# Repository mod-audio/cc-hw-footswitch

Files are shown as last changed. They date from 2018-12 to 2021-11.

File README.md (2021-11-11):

mod-hw-footswitch
=================

This repository contains the schematics and PCB design files for the Footswitch hardware.
This is a peripheral meant to be used in conjunction with MOD (http://moddevices.com/) via its control-chain interface.

These files were created and can be improved with KiCAD, a free software Electronics CAD which is available at http://www.kicad.org/

## Check out instructions ##

This project uses a set of KiCAD symbols and footprints provided by the official KiCad library (https://github.com/KiCad/). In order to properly fetch these dependencies, which are configured as submodule repositories, you have to use the **--recursive** attribute in the following **git** command:

> git clone --recursive https://github.com/portalmod/mod-hw-footswitch.git

## Licensing ##

This is an Open Hardware project and all of the files in this repository are licensed under the terms of the "Creative Commons By-SA" license.

## Firmware ##

The firmware source code is freely available at https://github.com/portalmod/mod-fw-footswitch

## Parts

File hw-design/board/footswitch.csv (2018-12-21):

Item | Qty | Reference(s) | Value | LibPart | Footprint | Datasheet | MPN | Note
1 | 9 | C1, C7, C9, C11, C12, C13, C14, C15, C21 | 100nF | footswitch-rescue:C | Capacitors_SMD:C_0603 | ~ | C1608X7R1E104K080AA
2 | 3 | C2, C8, C16 | 10uF | footswitch-rescue:C | Capacitors_SMD:C_0805 |  | GRM219R61E106KA12D
3 | 2 | C3, C17 | 1uF | footswitch-rescue:C | Capacitors_SMD:C_0805 |  | C2012X7R1E105K125AB
4 | 2 | C4, C6 | 18pF | footswitch-rescue:C | Capacitors_SMD:C_0603 |  | C1608C0G1H180J080AA
5 | 1 | C5 | 10uF | footswitch-rescue:CP1 | Capacitors_SMD:c_elec_5x5.3 | ~ | UWX1E100MCL1GB
6 | 1 | C10 | 100uF | footswitch-rescue:CP1 | Capacitors_SMD:c_elec_6.3x5.3 | ~ | UWX1C101MCL1GB
7 | 1 | C19 | 10nF 500V | footswitch-rescue:C | Capacitors_SMD:C_1206 |  | 501R18W103KV4E
8 | 1 | D1 | CGRA4007-G | footswitch-rescue:D | Diodes_SMD:Diode-SMA_Standard | ~ | CGRA4007-G
9 | 1 | D2 | 1N4148 | footswitch-rescue:D | Diodes_SMD:SOD-323 |  | 1N4148WX-TP
10 | 1 | D3 | 1N5819 | footswitch-rescue:D_Schottky | Diodes_SMD:SOD-123 |  | 1N5819HW-7-F
11 | 4 | D5, D6, D7, D8 | LED_RGB | footswitch-rescue:LED_RGB | LEDs:LED-RGB_PLLC-6 |  | LTRBGFSF-ABCB-QKYO-Z
12 | 2 | DS1, DS2 | ERM1602FS-6 3.3V | footswitch-rescue:RC1602A-GHW-ESX | local-footprints:WC1602A |  | ERM1602FS-6 3.3V | 3.3V display
13 | 6 | H1, H2, H3, H4, H5, H6 | HOLE | footswitch-rescue:CONN_01X01 | local-footprints:M3-screw-hole |  |  | not a component
14 | 2 | H7, H8 | KEYSTONE | footswitch-rescue:CONN_02X02 | local-footprints:Keystone-7790 |  | Keystone 7790
15 | 1 | J1 | CC_MAIN | footswitch-rescue:RJ45 | local-footprints:54602-908LF |  | 54602-908LF
16 | 1 | J2 | CC_NEXT | footswitch-rescue:RJ45 | local-footprints:54602-908LF |  | 54602-908LF
17 | 4 | P1, P2, P4, P5 | FOOT | footswitch-rescue:CONN_01X02 | Pin_Headers:Pin_Header_Angled_1x02 |  | M20-9960245 | place on the back side
18 | 1 | P3 | CHAIN | footswitch-rescue:CONN_01X03 | Pin_Headers:Pin_Header_Straight_1x03 |  |  | do not place
19 | 1 | P6 | CONN_01X12 | footswitch-rescue:CONN_01X12 | Pin_Headers:Pin_Header_Straight_1x12 |  | 68016-112HLF
20 | 1 | P7 | USB_OTG | footswitch-rescue:USB_OTG | Connect:USB_Mini-B |  | 10033526-N3212LF
21 | 1 | P8 | CONN_01X12 | footswitch-rescue:CONN_01X12 | Pin_Headers:Pin_Header_Angled_1x12 |  | 68016-112HLF
22 | 1 | P9 | SWD | footswitch-rescue:CONN_02X05 | Pin_Headers:Pin_Header_Straight_2x05_Pitch1.27mm |  |  | do not place
23 | 1 | P10 | CPU_RESET | footswitch-rescue:CONN_01X02 | Resistors_SMD:R_0402 |  |  | do not place
24 | 5 | Q1, Q3, Q4, Q7, Q8 | 2N7002 | footswitch-rescue:Q_NMOS_GSD | Housings_SOT-23_SOT-143_TSOT-6:SOT-23 |  | 2N7002P,215
25 | 1 | Q2 | BC857 | footswitch-rescue:Q_PNP_BEC | Housings_SOT-23_SOT-143_TSOT-6:SOT-23 |  | BC857B,215
26 | 1 | Q5 | FDN306P | footswitch-rescue:Q_PMOS_GSD | local-footprints:SOT-23-fairchild |  | FDN306P_F095
27 | 1 | Q6 | IRFML8244TRPBF | footswitch-rescue:Q_NMOS_GSD | Housings_SOT-23_SOT-143_TSOT-6:SOT-23 |  | IRFML8244TRPBF
28 | 13 | R1, R2, R3, R4, R8, R10, R11, R12, R13, R17, R18, R39, R40 | 10K | footswitch-rescue:R | Resistors_SMD:R_0603 | ~ | RMCF0603JT10K0
29 | 1 | R5 | 3K | footswitch-rescue:R | Resistors_SMD:R_0603 |  | MCR03ERTF3001
30 | 3 | R6, R19, R38 | 100K | footswitch-rescue:R | Resistors_SMD:R_0603 |  | RMCF0603JT100K
31 | 1 | R7 | 24K | footswitch-rescue:R | Resistors_SMD:R_0603 |  | MCR03ERTF2402
32 | 2 | R9, R21 | 2K4 | footswitch-rescue:R | Resistors_SMD:R_0603 |  |  | do not place
33 | 1 | R14 | 1K5 | footswitch-rescue:R | Resistors_SMD:R_0603 |  | MCR03ERTF1501
34 | 2 | R15, R22 | 1.2K | footswitch-rescue:R | Resistors_SMD:R_0603 |  | RMCF0603JT1K20
35 | 1 | R16 | 100R | footswitch-rescue:R | Resistors_SMD:R_0805 |  | ERJ-P06F1000V
36 | 1 | R20 | 100R | footswitch-rescue:R | Resistors_SMD:R_0603 |  | RMCF0603JT100R
37 | 12 | R23, R24, R25, R28, R29, R30, R31, R32, R33, R34, R35, R36 | 220R | footswitch-rescue:R | Resistors_SMD:R_0603 | ~ | RMCF0603JT220R
38 | 2 | R26, R27 | 33R | footswitch-rescue:R | Resistors_SMD:R_0603 |  | MCR03ERTF33R0
39 | 1 | R37 | 1M | footswitch-rescue:R | Resistors_SMD:R_0603 |  | RMCF0603JT1M00
40 | 1 | RT1 | PTC_FUSE | footswitch-rescue:FUSE | Resistors_SMD:R_1210 | ~ | 0ZCB0050FF2G
41 | 1 | U1 | ISL83491 | footswitch-rescue:ISL83491 | Housings_SOIC:SOIC-14_3.9x8.7mm_Pitch1.27mm |  | ISL83491IBZ
42 | 1 | U2 | NCP1117DT33G | footswitch-rescue:NCP1117ST33T3G | SMD_Packages:DPAK-2 |  | NCP1117DT33G
43 | 1 | U3 | LPC11U24FBD48/401 | footswitch-rescue:LPC11U24FBD48_401 | Housings_QFP:LQFP-48_7x7mm_Pitch0.5mm |  | LPC11U24FBD48/401
44 | 1 | Y1 | 12MHz | footswitch-rescue:Crystal_Small | Crystals:Crystal_HC49-SD_SMD |  | FOXSDLF/120-20

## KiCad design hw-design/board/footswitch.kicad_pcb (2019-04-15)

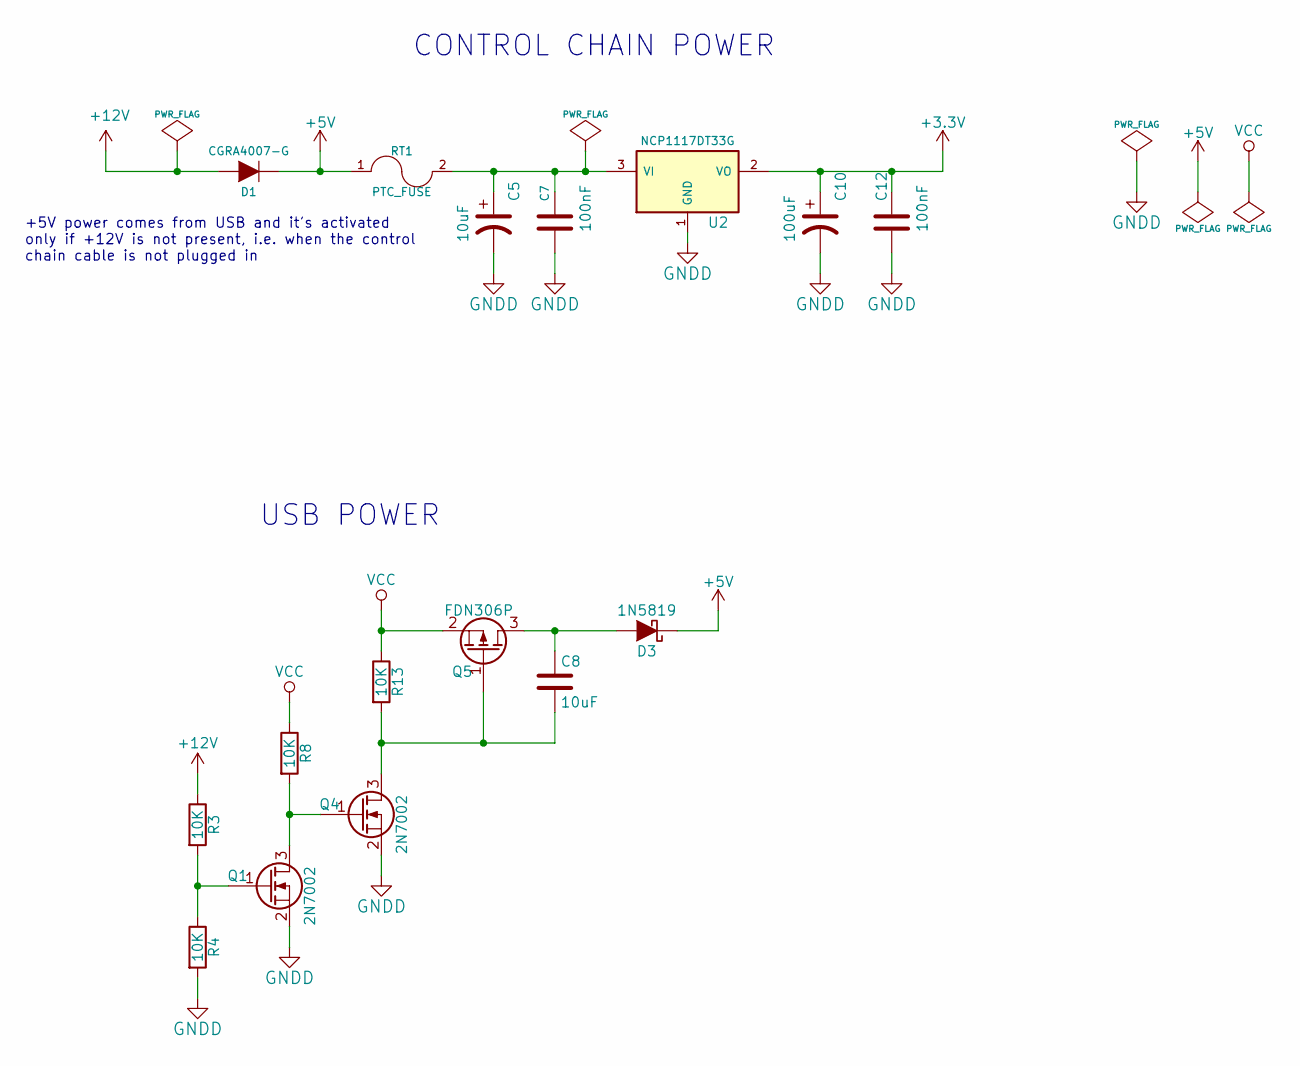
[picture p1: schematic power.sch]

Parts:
C5: 10uF; c_elec_5x5.3; MPN UWX1E100MCL1GB
C7, C12: 100nF; C_0603; MPN C1608X7R1E104K080AA
C8: 10uF; C_0805; MPN GRM219R61E106KA12D
C10: 100uF; c_elec_6.3x5.3; MPN UWX1C101MCL1GB
D1: CGRA4007-G; Diode-SMA_Standard; MPN CGRA4007-G
D3: 1N5819; SOD-123; MPN 1N5819HW-7-F
Q1, Q4: 2N7002; SOT-23; MPN 2N7002P,215
Q5: FDN306P; SOT-23-fairchild; MPN FDN306P_F095
R3, R4, R8, R13: 10K; R_0603; MPN RMCF0603JT10K0
RT1: PTC_FUSE; R_1210; MPN 0ZCB0050FF2G
U2: NCP1117DT33G; DPAK-2; MPN NCP1117DT33G

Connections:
+3V3: C10.1, C12.1, U2.2 (VO); also elsewhere on the board
+5V: D1.1 (K), D3.1 (K), RT1.1
+12V: D1.2 (A), R3.1; also elsewhere on the board
GNDD: C5.2, C7.2, C10.2, C12.2, Q1.2 (S), Q4.2 (S), R4.2, U2.1 (GND); also elsewhere on the board
unnamed: C5.1, C7.1, RT1.2, U2.3 (VI)
unnamed: C8.1, D3.2 (A), Q5.3 (D)
unnamed: C8.2, Q4.3 (D), Q5.1 (G), R13.2
unnamed: Q1.1 (G), R3.2, R4.1
unnamed: Q1.3 (D), Q4.1 (G), R8.2
USB_VCC: Q5.2 (S), R8.1, R13.1; also elsewhere on the board

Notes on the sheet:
CONTROL CHAIN POWER
USB POWER
+5V power comes from USB and it's activated only if +12V is not present, i.e. when the control chain cable is not plugged in

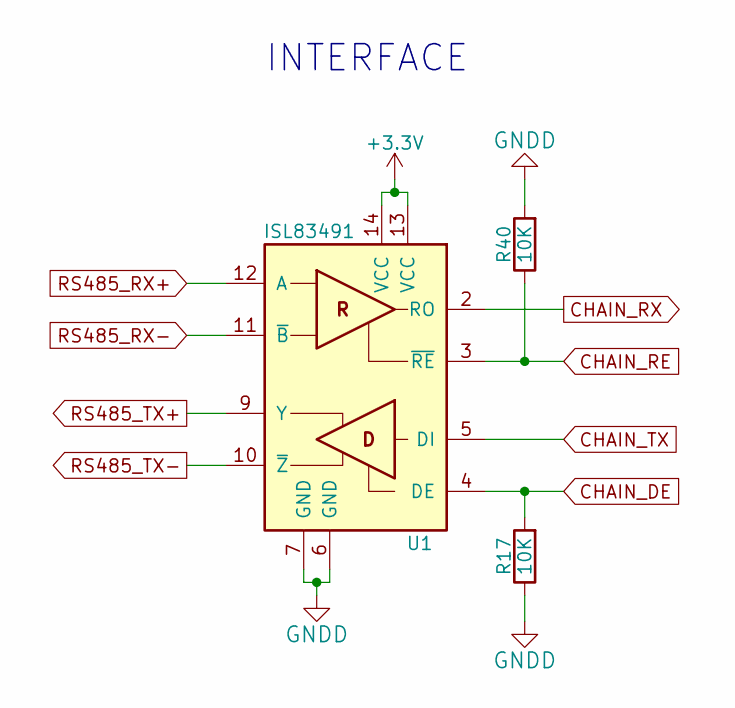
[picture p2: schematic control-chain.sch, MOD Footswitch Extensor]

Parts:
R17, R40: 10K; R_0603; MPN RMCF0603JT10K0
U1: ISL83491; SOIC-14_3.9x8.7mm_Pitch1.27mm; MPN ISL83491IBZ

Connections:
+3V3: U1.13 (VCC), U1.14 (VCC); also elsewhere on the board
CHAIN_DE: R17.2, U1.4 (DE); also elsewhere on the board
CHAIN_RE: R40.1, U1.3 (~RE); also elsewhere on the board
CHAIN_RX: U1.2 (RO); also elsewhere on the board
CHAIN_TX: U1.5 (DI); also elsewhere on the board
GNDD: R17.1, R40.2, U1.6 (GND), U1.7 (GND); also elsewhere on the board
RS485_RX+: U1.12 (A); also elsewhere on the board
RS485_RX-: U1.11 (~B); also elsewhere on the board
RS485_TX+: U1.9 (Y); also elsewhere on the board
RS485_TX-: U1.10 (~Z~); also elsewhere on the board

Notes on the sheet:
INTERFACE

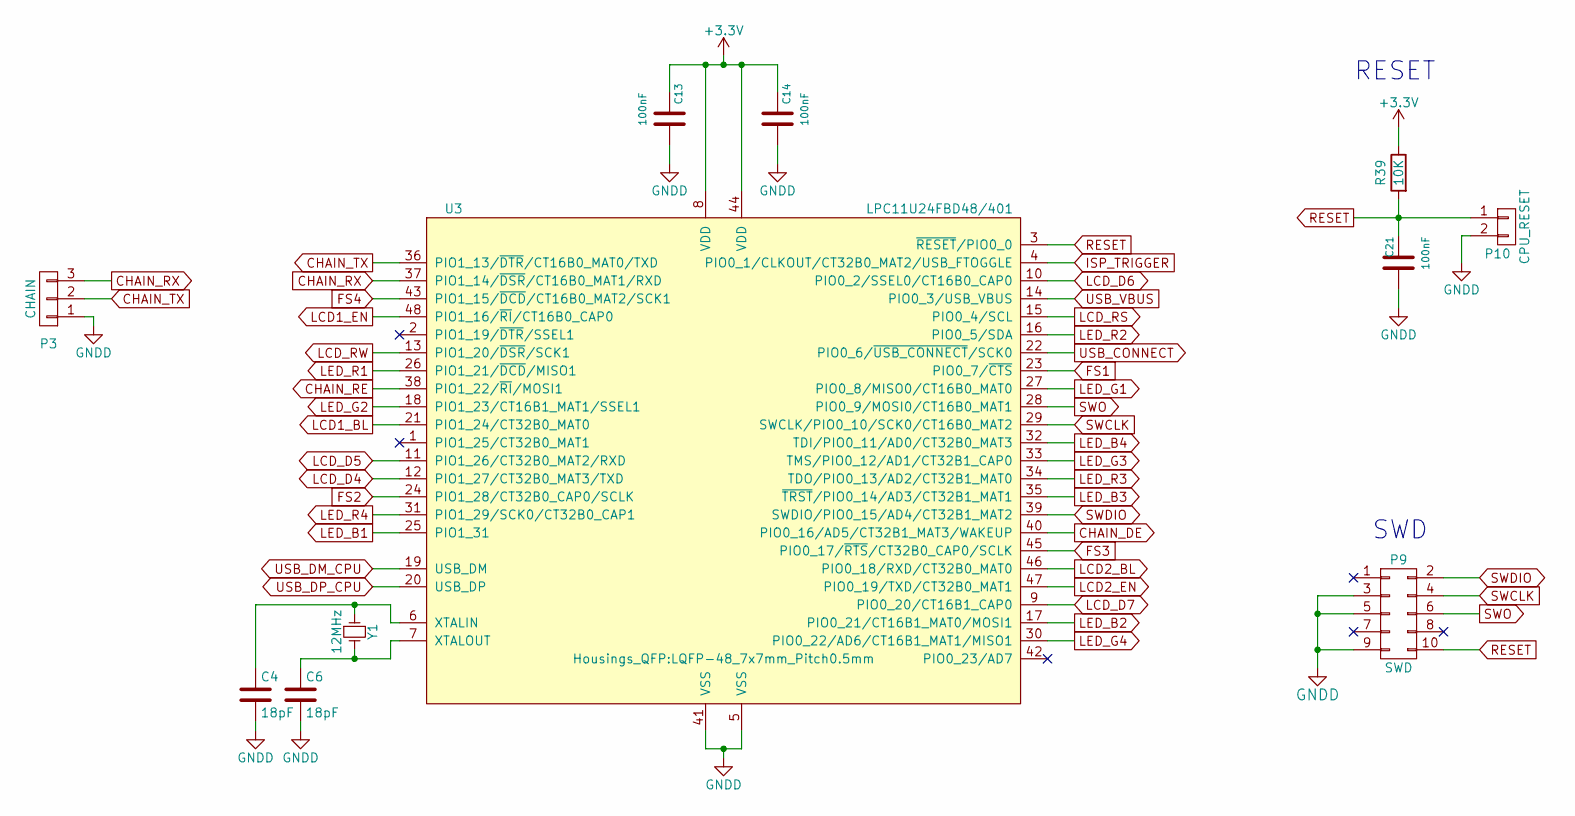
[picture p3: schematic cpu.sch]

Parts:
C4, C6: 18pF; C_0603; MPN C1608C0G1H180J080AA
C13, C14, C21: 100nF; C_0603; MPN C1608X7R1E104K080AA
P3: CHAIN; Pin_Header_Straight_1x03
P9: SWD; Pin_Header_Straight_2x05_Pitch1.27mm
P10: CPU_RESET; R_0402
R39: 10K; R_0603; MPN RMCF0603JT10K0
U3: LPC11U24FBD48/401; LQFP-48_7x7mm_Pitch0.5mm; MPN LPC11U24FBD48/401
Y1: 12MHz; Crystal_HC49-SD_SMD; MPN FOXSDLF/120-20

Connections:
+3V3: C13.2, C14.2, R39.1, U3.8 (VDD), U3.44 (VDD); also elsewhere on the board
CHAIN_DE: U3.40 (PIO0_16/AD5/CT32B1_MAT3/WAKEUP); also elsewhere on the board
CHAIN_RE: U3.38 (PIO1_22/~RI~/MOSI1); also elsewhere on the board
CHAIN_RX: P3.3, U3.37 (PIO1_14/~DSR~/CT16B0_MAT1/RXD); also elsewhere on the board
CHAIN_TX: P3.2, U3.36 (PIO1_13/~DTR~/CT16B0_MAT0/TXD); also elsewhere on the board
FS1: U3.23 (PIO0_7/~CTS~); also elsewhere on the board
FS2: U3.24 (PIO1_28/CT32B0_CAP0/SCLK); also elsewhere on the board
FS3: U3.45 (PIO0_17/~RTS~/CT32B0_CAP0/SCLK); also elsewhere on the board
FS4: U3.43 (PIO1_15/~DCD~/CT16B0_MAT2/SCK1); also elsewhere on the board
GNDD: C4.2, C6.2, C13.1, C14.1, C21.1, P3.1, P9.3, P9.5, P9.9, P10.2, U3.5 (VSS), U3.41 (VSS); also elsewhere on the board
ISP_TRIGGER: U3.4 (PIO0_1/CLKOUT/CT32B0_MAT2/USB_FTOGGLE); also elsewhere on the board
LCD1_BL: U3.21 (PIO1_24/CT32B0_MAT0); also elsewhere on the board
LCD1_EN: U3.48 (PIO1_16/~RI~/CT16B0_CAP0); also elsewhere on the board
LCD2_BL: U3.46 (PIO0_18/RXD/CT32B0_MAT0); also elsewhere on the board
LCD2_EN: U3.47 (PIO0_19/TXD/CT32B0_MAT1); also elsewhere on the board
LCD_D4: U3.12 (PIO1_27/CT32B0_MAT3/TXD); also elsewhere on the board
LCD_D5: U3.11 (PIO1_26/CT32B0_MAT2/RXD); also elsewhere on the board
LCD_D6: U3.10 (PIO0_2/SSEL0/CT16B0_CAP0); also elsewhere on the board
LCD_D7: U3.9 (PIO0_20/CT16B1_CAP0); also elsewhere on the board
LCD_RS: U3.15 (PIO0_4/SCL); also elsewhere on the board
LCD_RW: U3.13 (PIO1_20/~DSR~/SCK1); also elsewhere on the board
LED_B1: U3.25 (PIO1_31); also elsewhere on the board
LED_B2: U3.17 (PIO0_21/CT16B1_MAT0/MOSI1); also elsewhere on the board
LED_B3: U3.35 (~TRST~/PIO0_14/AD3/CT32B1_MAT1); also elsewhere on the board
LED_B4: U3.32 (TDI/PIO0_11/AD0/CT32B0_MAT3); also elsewhere on the board
LED_G1: U3.27 (PIO0_8/MISO0/CT16B0_MAT0); also elsewhere on the board
LED_G2: U3.18 (PIO1_23/CT16B1_MAT1/SSEL1); also elsewhere on the board
LED_G3: U3.33 (TMS/PIO0_12/AD1/CT32B1_CAP0); also elsewhere on the board
LED_G4: U3.30 (PIO0_22/AD6/CT16B1_MAT1/MISO1); also elsewhere on the board
LED_R1: U3.26 (PIO1_21/~DCD~/MISO1); also elsewhere on the board
LED_R2: U3.16 (PIO0_5/SDA); also elsewhere on the board
LED_R3: U3.34 (TDO/PIO0_13/AD2/CT32B1_MAT0); also elsewhere on the board
LED_R4: U3.31 (PIO1_29/SCK0/CT32B0_CAP1); also elsewhere on the board
unnamed: C4.1, U3.6 (XTALIN), Y1.1
unnamed: C6.1, U3.7 (XTALOUT), Y1.2
RESET: C21.2, P9.10, P10.1, R39.2, U3.3 (~RESET~/PIO0_0)
SWCLK: P9.4, U3.29 (SWCLK/PIO0_10/SCK0/CT16B0_MAT2)
SWDIO: P9.2, U3.39 (SWDIO/PIO0_15/AD4/CT32B1_MAT2)
SWO: P9.6, U3.28 (PIO0_9/MOSI0/CT16B0_MAT1)
USB_CONNECT: U3.22 (PIO0_6/~USB_CONNECT~/SCK0); also elsewhere on the board
USB_DM_CPU: U3.19 (USB_DM); also elsewhere on the board
USB_DP_CPU: U3.20 (USB_DP); also elsewhere on the board
USB_VBUS: U3.14 (PIO0_3/USB_VBUS); also elsewhere on the board

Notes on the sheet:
SWD
RESET

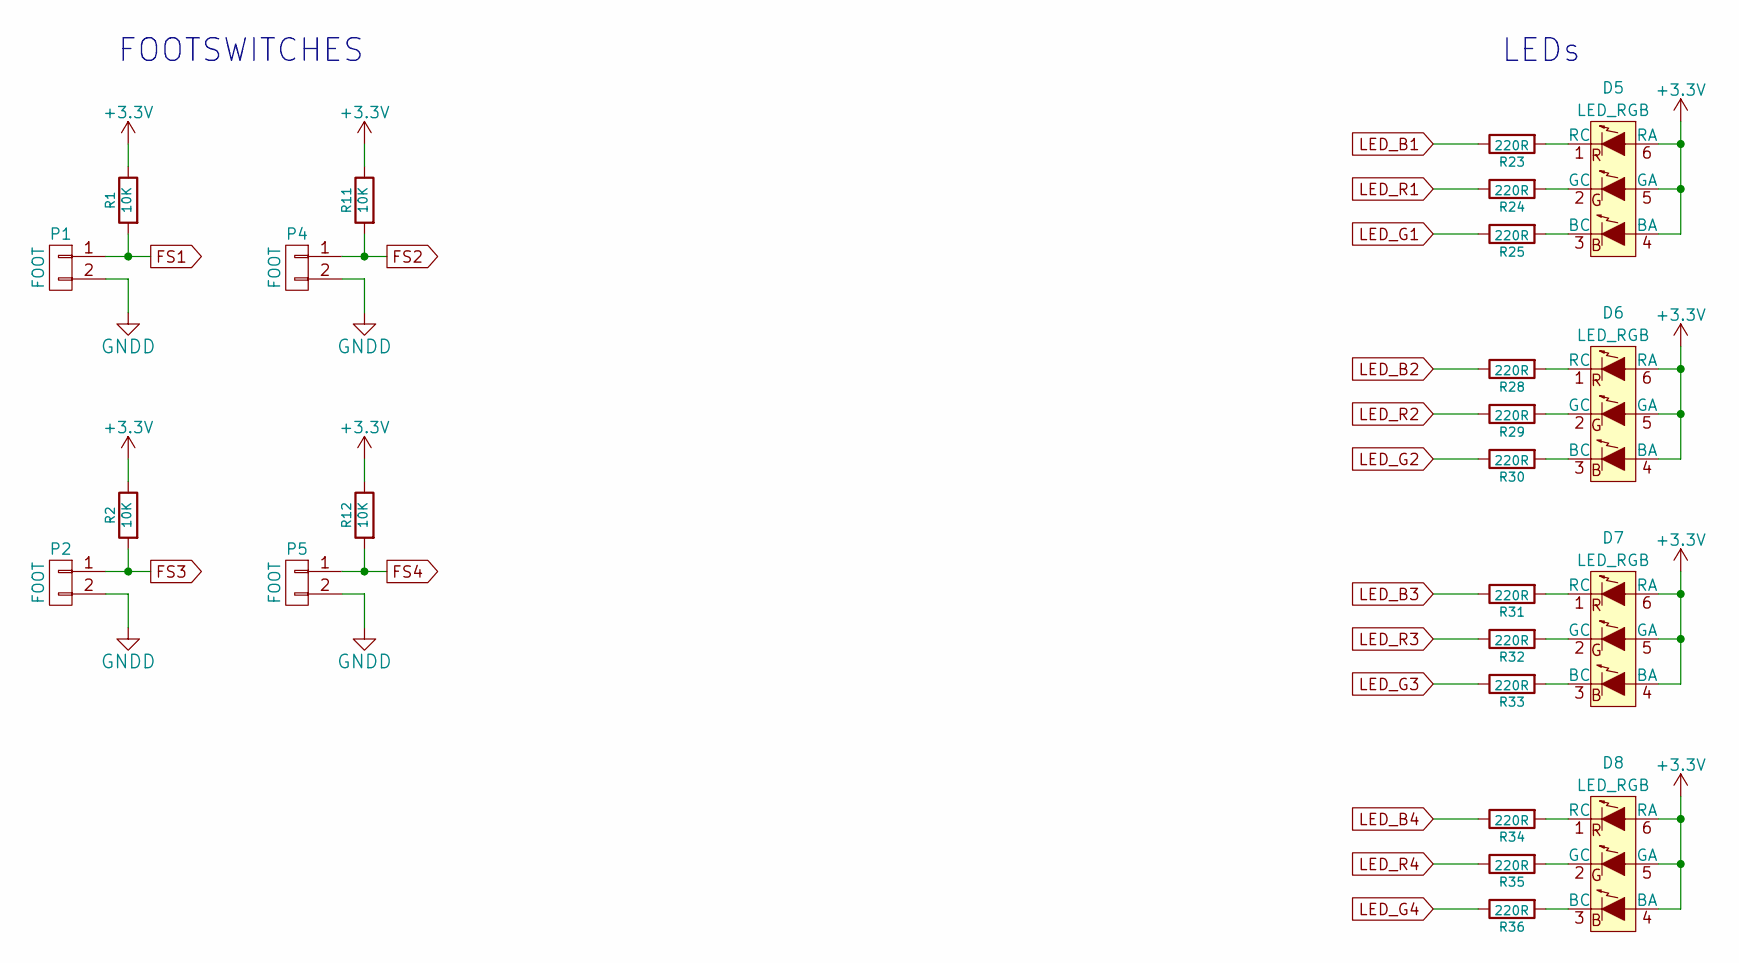
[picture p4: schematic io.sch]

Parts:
D5, D6, D7, D8: LED_RGB; LED-RGB_PLLC-6; MPN LTRBGFSF-ABCB-QKYO-Z
P1, P2, P4, P5: FOOT; Pin_Header_Angled_1x02; MPN M20-9960245
R1, R2, R11, R12: 10K; R_0603; MPN RMCF0603JT10K0
R23, R24, R25, R28, R29, R30, R31, R32, R33, R34, R35, R36: 220R; R_0603; MPN RMCF0603JT220R

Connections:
+3V3: D5.4 (BA), D5.5 (GA), D5.6 (RA), D6.4 (BA), D6.5 (GA), D6.6 (RA), D7.4 (BA), D7.5 (GA), D7.6 (RA), D8.4 (BA), D8.5 (GA), D8.6 (RA), R1.1, R2.1, R11.1, R12.1; also elsewhere on the board
FS1: P1.1, R1.2; also elsewhere on the board
FS2: P4.1, R11.2; also elsewhere on the board
FS3: P2.1, R2.2; also elsewhere on the board
FS4: P5.1, R12.2; also elsewhere on the board
GNDD: P1.2, P2.2, P4.2, P5.2; also elsewhere on the board
LED_B1: R23.1; also elsewhere on the board
LED_B2: R28.1; also elsewhere on the board
LED_B3: R31.1; also elsewhere on the board
LED_B4: R34.1; also elsewhere on the board
LED_G1: R25.1; also elsewhere on the board
LED_G2: R30.1; also elsewhere on the board
LED_G3: R33.1; also elsewhere on the board
LED_G4: R36.1; also elsewhere on the board
LED_R1: R24.1; also elsewhere on the board
LED_R2: R29.1; also elsewhere on the board
LED_R3: R32.1; also elsewhere on the board
LED_R4: R35.1; also elsewhere on the board
unnamed: D5.1 (RC), R23.2
unnamed: D5.2 (GC), R24.2
unnamed: D5.3 (BC), R25.2
unnamed: D6.1 (RC), R28.2
unnamed: D6.2 (GC), R29.2
unnamed: D6.3 (BC), R30.2
unnamed: D7.1 (RC), R31.2
unnamed: D7.2 (GC), R32.2
unnamed: D7.3 (BC), R33.2
unnamed: D8.1 (RC), R34.2
unnamed: D8.2 (GC), R35.2
unnamed: D8.3 (BC), R36.2

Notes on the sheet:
FOOTSWITCHES
LEDs

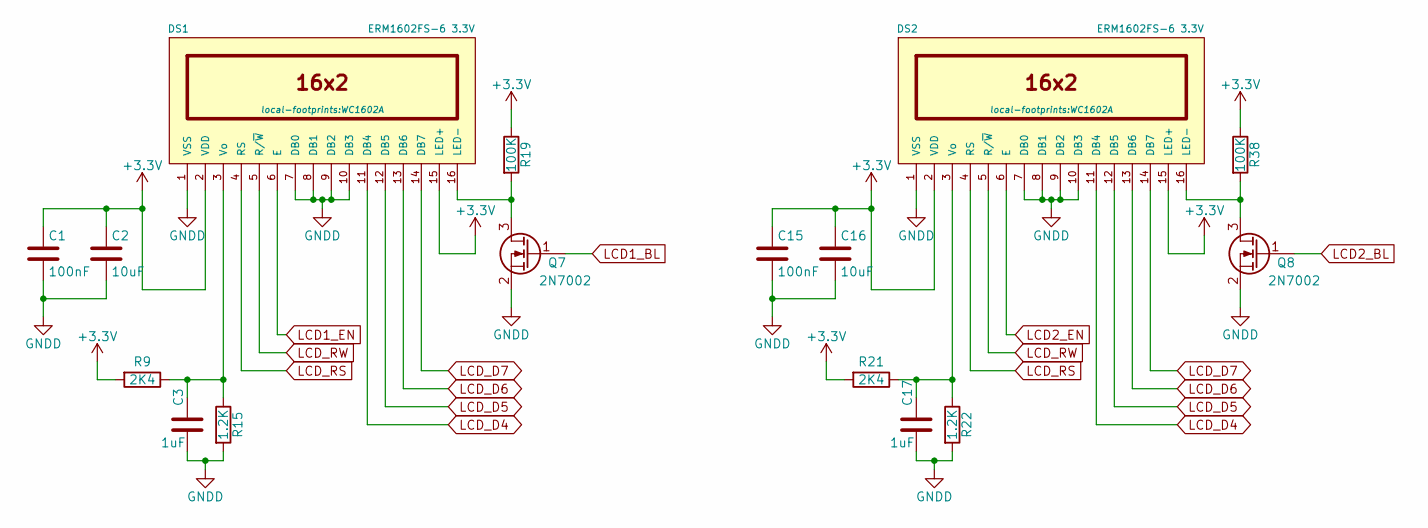
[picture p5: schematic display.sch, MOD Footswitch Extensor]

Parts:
C1, C15: 100nF; C_0603; MPN C1608X7R1E104K080AA
C2, C16: 10uF; C_0805; MPN GRM219R61E106KA12D
C3, C17: 1uF; C_0805; MPN C2012X7R1E105K125AB
DS1, DS2: ERM1602FS-6 3.3V; WC1602A; MPN ERM1602FS-6 3.3V
Q7, Q8: 2N7002; SOT-23; MPN 2N7002P,215
R9, R21: 2K4; R_0603
R15, R22: 1.2K; R_0603; MPN RMCF0603JT1K20
R19, R38: 100K; R_0603; MPN RMCF0603JT100K

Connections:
+3V3: C1.1, C2.1, C15.1, C16.1, DS1.2 (VDD), DS1.15 (LED+), DS2.2 (VDD), DS2.15 (LED+), R9.2, R19.1, R21.2, R38.1; also elsewhere on the board
GNDD: C1.2, C2.2, C3.2, C15.2, C16.2, C17.2, DS1.1 (VSS), DS1.7 (DB0), DS1.8 (DB1), DS1.9 (DB2), DS1.10 (DB3), DS2.1 (VSS), DS2.7 (DB0), DS2.8 (DB1), DS2.9 (DB2), DS2.10 (DB3), Q7.2 (S), Q8.2 (S), R15.2, R22.2; also elsewhere on the board
LCD1_BL: Q7.1 (G); also elsewhere on the board
LCD1_EN: DS1.6 (E); also elsewhere on the board
LCD2_BL: Q8.1 (G); also elsewhere on the board
LCD2_EN: DS2.6 (E); also elsewhere on the board
LCD_D4: DS1.11 (DB4), DS2.11 (DB4); also elsewhere on the board
LCD_D5: DS1.12 (DB5), DS2.12 (DB5); also elsewhere on the board
LCD_D6: DS1.13 (DB6), DS2.13 (DB6); also elsewhere on the board
LCD_D7: DS1.14 (DB7), DS2.14 (DB7); also elsewhere on the board
LCD_RS: DS1.4 (RS), DS2.4 (RS); also elsewhere on the board
LCD_RW: DS1.5 (R/~W), DS2.5 (R/~W); also elsewhere on the board
unnamed: C3.1, DS1.3 (Vo), R9.1, R15.1
unnamed: C17.1, DS2.3 (Vo), R21.1, R22.1
unnamed: DS1.16 (LED-), Q7.3 (D), R19.2
unnamed: DS2.16 (LED-), Q8.3 (D), R38.2

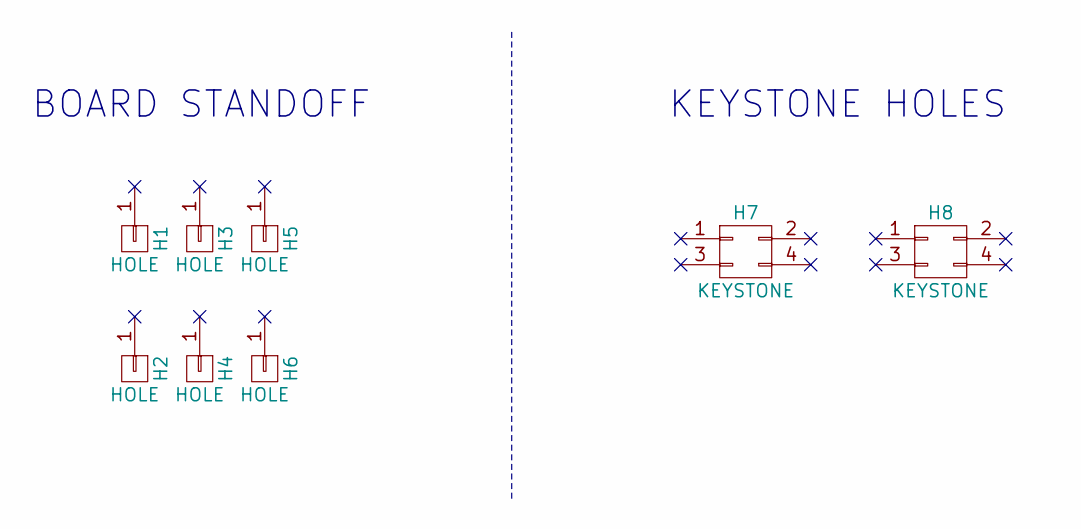
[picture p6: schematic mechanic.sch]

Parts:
H1, H2, H3, H4, H5, H6: HOLE; M3-screw-hole
H7, H8: KEYSTONE; Keystone-7790; MPN Keystone 7790

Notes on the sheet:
BOARD STANDOFF
KEYSTONE HOLES

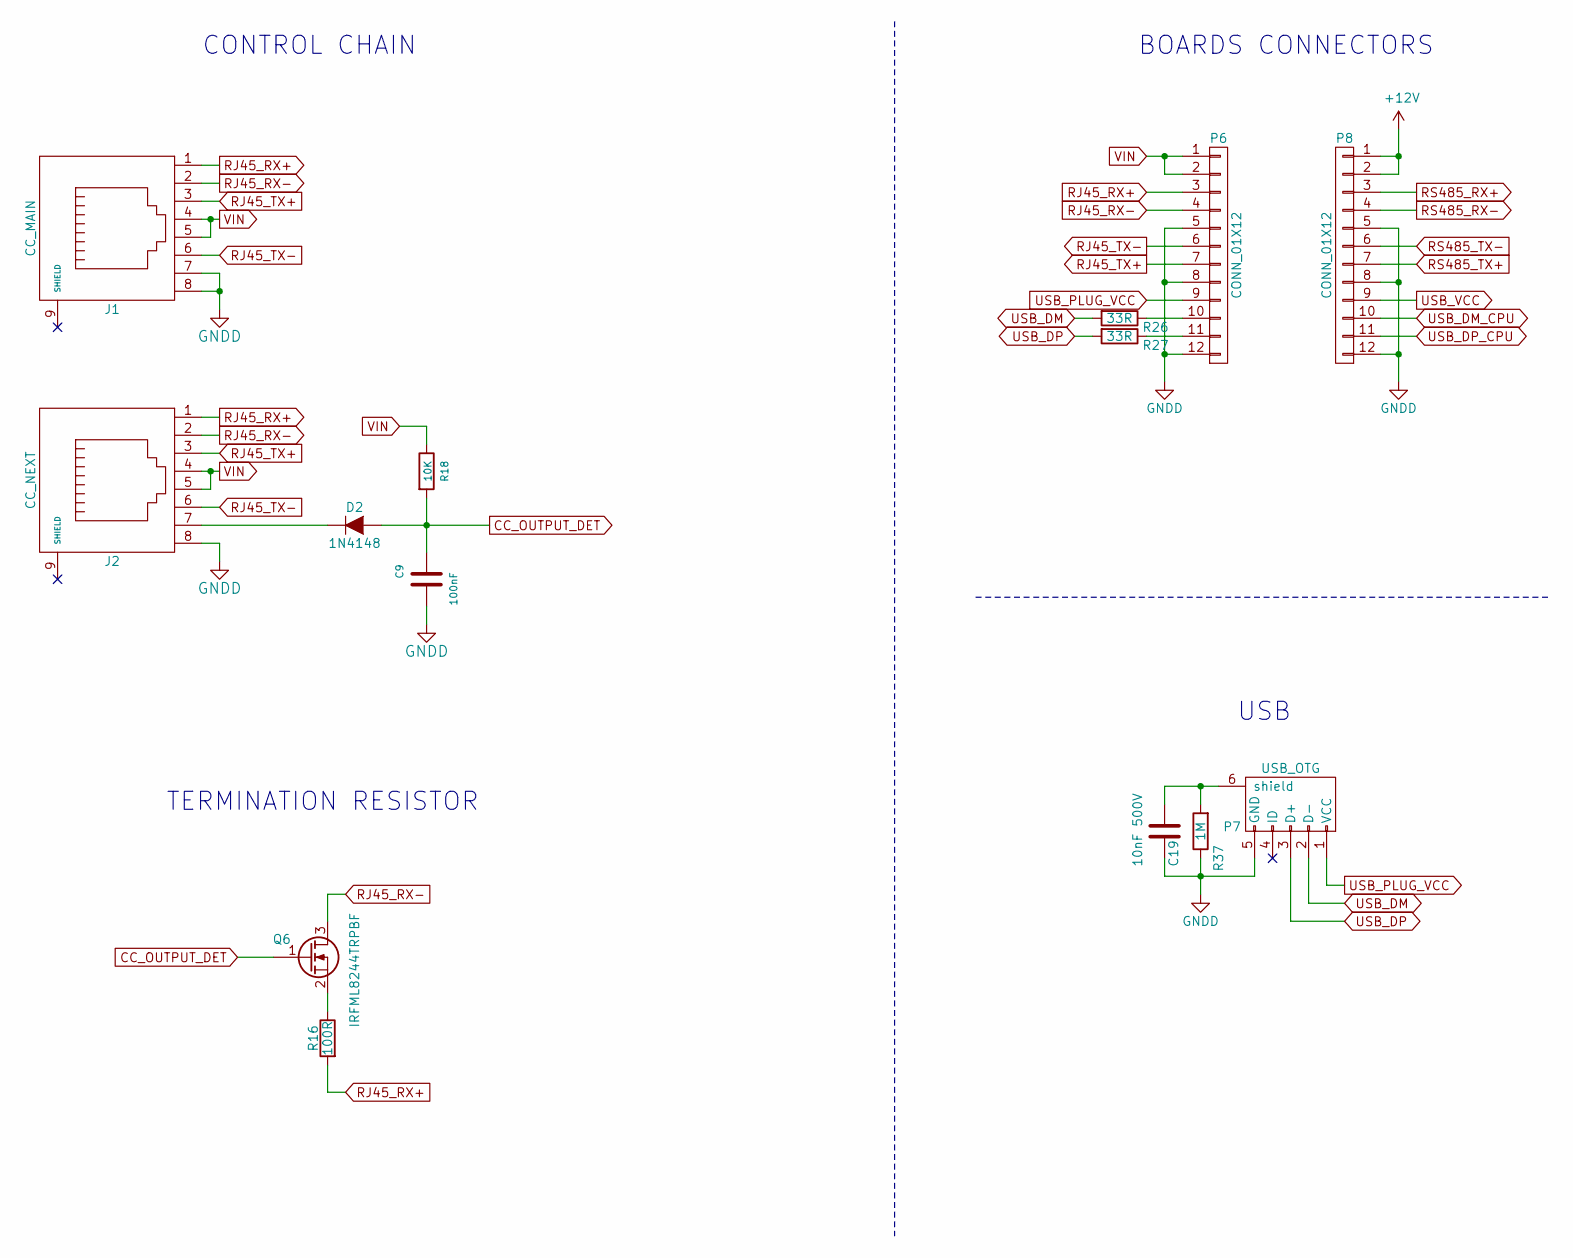
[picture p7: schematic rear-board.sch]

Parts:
C9: 100nF; C_0603; MPN C1608X7R1E104K080AA
C19: 10nF 500V; C_1206; MPN 501R18W103KV4E
D2: 1N4148; SOD-323; MPN 1N4148WX-TP
J1: CC_MAIN; 54602-908LF; MPN 54602-908LF
J2: CC_NEXT; 54602-908LF; MPN 54602-908LF
P6: CONN_01X12; Pin_Header_Straight_1x12; MPN 68016-112HLF
P7: USB_OTG; USB_Mini-B; MPN 10033526-N3212LF
P8: CONN_01X12; Pin_Header_Angled_1x12; MPN 68016-112HLF
Q6: IRFML8244TRPBF; SOT-23; MPN IRFML8244TRPBF
R16: 100R; R_0805; MPN ERJ-P06F1000V
R18: 10K; R_0603; MPN RMCF0603JT10K0
R26, R27: 33R; R_0603; MPN MCR03ERTF33R0
R37: 1M; R_0603; MPN RMCF0603JT1M00

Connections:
+12V: P8.1, P8.2; also elsewhere on the board
CC_OUTPUT_DET: C9.1, D2.2 (A), Q6.1 (G), R18.2
GNDD: C9.2, C19.2, J1.7, J1.8, J2.8, P6.5, P6.8, P6.12, P7.5 (GND), P8.5, P8.8, P8.12, R37.1; also elsewhere on the board
unnamed: C19.1, P7.6 (shield), R37.2
unnamed: D2.1 (K), J2.7
unnamed: P6.10, R26.1
unnamed: P6.11, R27.1
unnamed: Q6.2 (S), R16.1
RJ45_RX+: J1.1, J2.1, P6.3, R16.2
RJ45_RX-: J1.2, J2.2, P6.4, Q6.3 (D)
RJ45_TX+: J1.3, J2.3, P6.7
RJ45_TX-: J1.6, J2.6, P6.6
RS485_RX+: P8.3; also elsewhere on the board
RS485_RX-: P8.4; also elsewhere on the board
RS485_TX+: P8.7; also elsewhere on the board
RS485_TX-: P8.6; also elsewhere on the board
USB_DM: P7.2 (D-), R26.2
USB_DM_CPU: P8.10; also elsewhere on the board
USB_DP: P7.3 (D+), R27.2
USB_DP_CPU: P8.11; also elsewhere on the board
USB_PLUG_VCC: P6.9, P7.1 (VCC)
USB_VCC: P8.9; also elsewhere on the board
VIN: J1.4, J1.5, J2.4, J2.5, P6.1, P6.2, R18.1

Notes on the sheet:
CONTROL CHAIN
USB
TERMINATION RESISTOR
BOARDS CONNECTORS

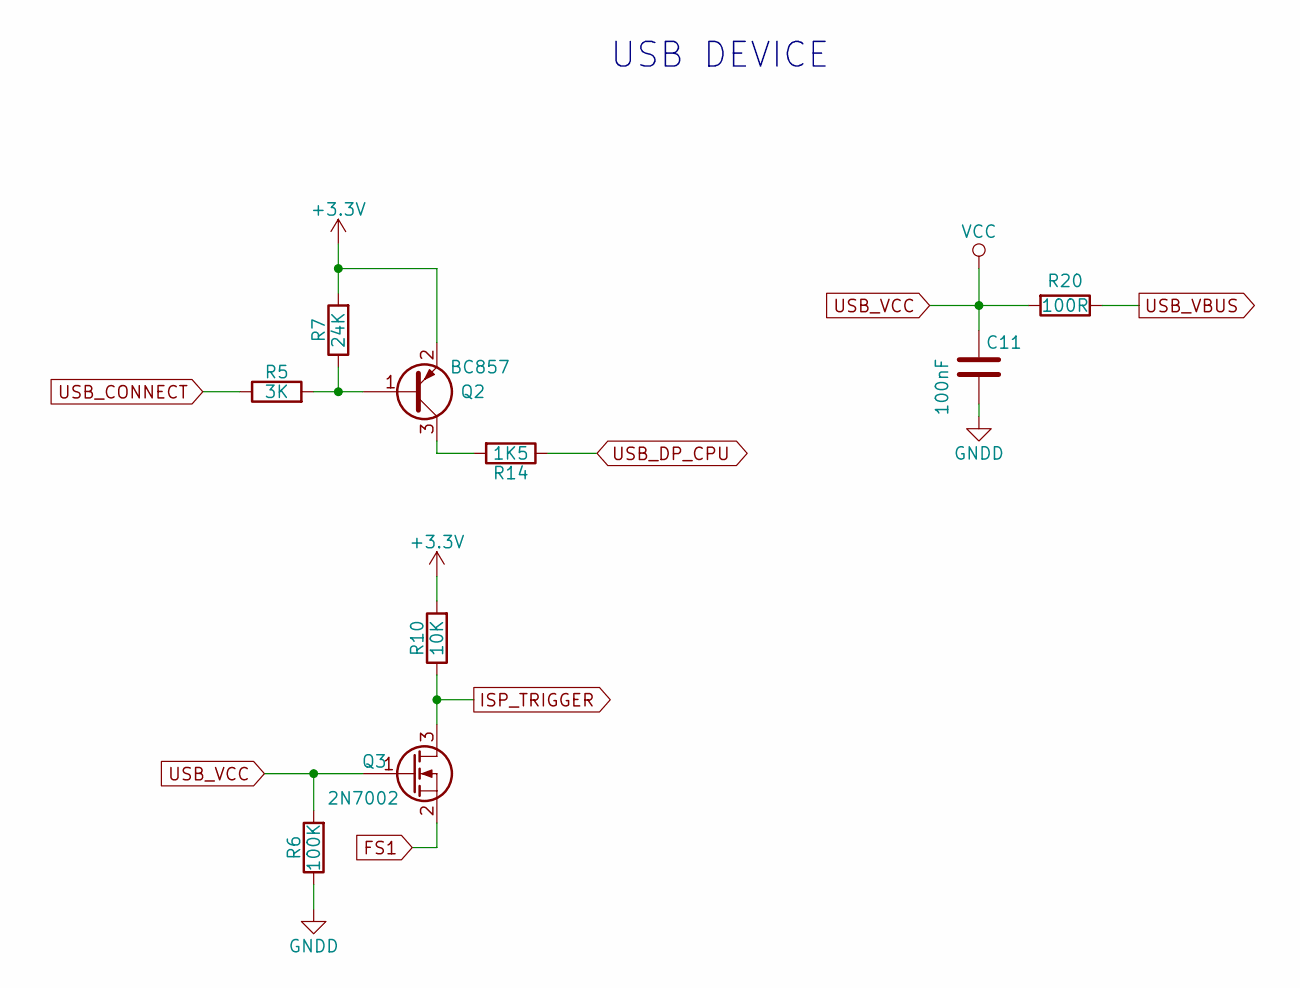
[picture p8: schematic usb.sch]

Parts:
C11: 100nF; C_0603; MPN C1608X7R1E104K080AA
Q2: BC857; SOT-23; MPN BC857B,215
Q3: 2N7002; SOT-23; MPN 2N7002P,215
R5: 3K; R_0603; MPN MCR03ERTF3001
R6: 100K; R_0603; MPN RMCF0603JT100K
R7: 24K; R_0603; MPN MCR03ERTF2402
R10: 10K; R_0603; MPN RMCF0603JT10K0
R14: 1K5; R_0603; MPN MCR03ERTF1501
R20: 100R; R_0603; MPN RMCF0603JT100R

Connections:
+3V3: Q2.2 (E), R7.2, R10.2; also elsewhere on the board
FS1: Q3.2 (S); also elsewhere on the board
GNDD: C11.2, R6.1; also elsewhere on the board
ISP_TRIGGER: Q3.3 (D), R10.1; also elsewhere on the board
unnamed: Q2.1 (B), R5.2, R7.1
unnamed: Q2.3 (C), R14.2
USB_CONNECT: R5.1; also elsewhere on the board
USB_DP_CPU: R14.1; also elsewhere on the board
USB_VBUS: R20.1; also elsewhere on the board
USB_VCC: C11.1, Q3.1 (G), R6.2, R20.2; also elsewhere on the board

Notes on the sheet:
USB DEVICE

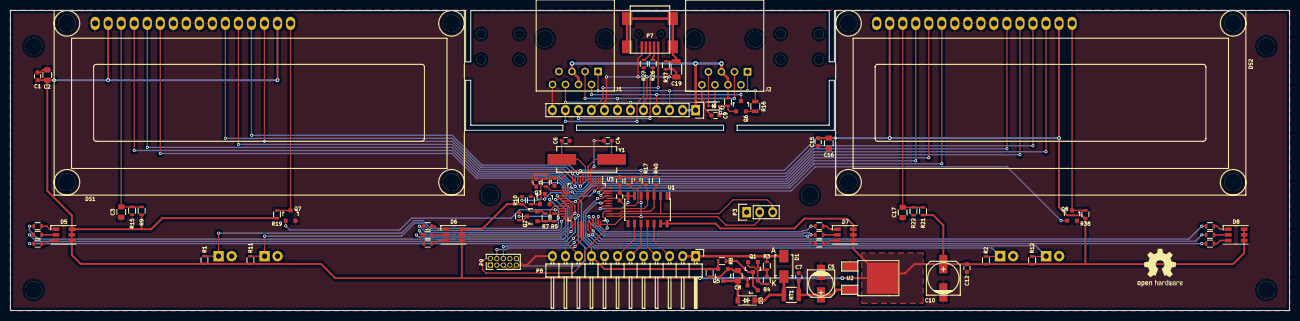
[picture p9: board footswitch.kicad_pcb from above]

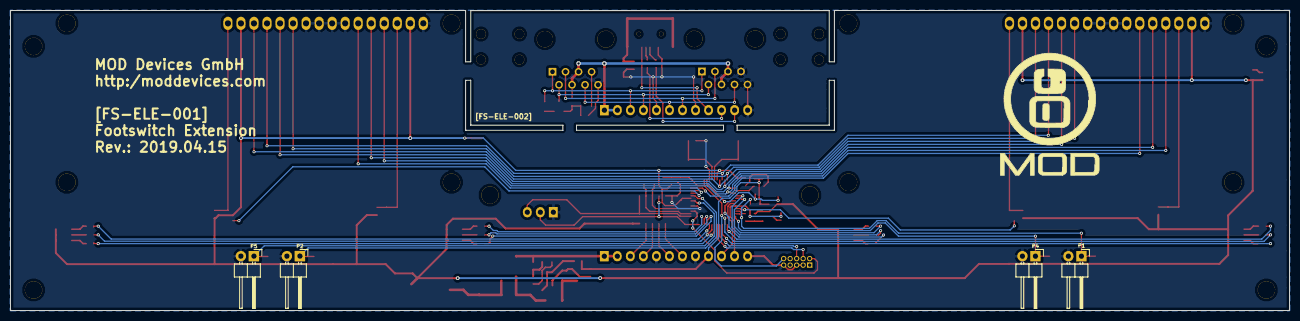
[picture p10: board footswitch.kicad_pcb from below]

Board: 2 copper layers, 249.4 x 58.5 mm, 102 parts (4 on the bottom side), 87 nets.

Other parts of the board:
LOGO1: Logo_Open_Hardware_Small; OSHW-Logo2_9.8x8mm_SilkScreen

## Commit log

2014-05-15 Initial commit of MOD Foot. MOD_Foot_Prototype1.
    [BOM-Mod-Foot-Prototype1.xls, Display.sch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]
2014-06-03 BOM for ITEAD quotes.
    [BOM_MOD_Foot_Prototpe1.xls, BOM_MOD_Foot_Prototpe1_2014.06.03.xls, Display.sch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]
2014-06-04 Solved schematic diagram of rs422 protection zener diodes.
    [MOD_Foot_Prototype1.sch]
2014-06-16 Created BOM with ITEAD template.
    [BOM_MOD_Foot_Prototpe1.xls, BOM_MOD_Foot_Prototpe1_Template_ITEAD_2014.06.16.xls, MOD_Foot_Prototype1.csv]
2014-12-02 fix issue #14: Broken component/footprint map file This commit makes the mod-arduino-shield a dependency. We must still move the footprint library to a single repository and declare it properly as a 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
    [Display.sch, MOD_Foot_Prototype1.kicad_pcb, MOD_Foot_Prototype1.sch]
2014-12-02 removing local footprint library and adding a submodule to use the footprint library available at the https://github.com/portalmod/mod-kicad-footprints repository.
    [Display.sch, MOD_Foot_Prototype1.sch]
2014-12-02 update footprint lib references in the kicad_pcb file as well... (and a relative path in the netlist file)
    [MOD_Foot_Prototype1.kicad_pcb]
2014-12-05 grounding the mechanical connectors (and regenerating Gerber files)
    [MOD_Foot_Prototype1-B_Cu.gbl, MOD_Foot_Prototype1-B_Mask.gbs, MOD_Foot_Prototype1-B_SilkS.gbo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]
2014-12-05 removing redundant Gerber files (Gerber/ITEAD/ subdir)
    [MOD_Foot_Prototype1.GBL, MOD_Foot_Prototype1.GBO, MOD_Foot_Prototype1.GBS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]
2014-12-05 Bringing back the positioning of references and values that were messed up with in the recent refactoring.
    [MOD_Foot_Prototype1-B_Cu.gbl, MOD_Foot_Prototype1-B_Mask.gbs, MOD_Foot_Prototype1-B_SilkS.gbo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]
2014-12-08 rearrange R38 and C3 components (fix issue #7)
    [MOD_Foot_Prototype1-B_Cu.gbl, MOD_Foot_Prototype1-B_Mask.gbs, MOD_Foot_Prototype1-B_SilkS.gbo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]
2014-12-08 fixing LED labels in the schematics (they are output signals, not inputs).
    [MOD_Foot_Prototype1.sch]
2014-12-08 wip issue #13 - changing schematics We're freeing the AD5/PIO1_4 and AD7/PIO1_11 pins. LED1_B and LED1_R, which used these, will now use PIO3_5 and PIO3_4, respectively.
    [MOD_Foot_Prototype1.sch]
2014-12-08 updating pcb traces (fixes issue #13: ADC availability)
    [MOD_Foot_Prototype1-B_Cu.gbl, MOD_Foot_Prototype1-B_Mask.gbs, MOD_Foot_Prototype1-B_SilkS.gbo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]
2014-12-09 wip issue #11: protect the U4 IC when the board is being debugged - made the changes in the schematics
    [MOD_Foot_Prototype1.sch]
2014-12-09 fix issue #11: protect the U4 IC when the board is being debugged Updated PCB traces and regenerated Gerbers.
    [Display.sch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]
2014-12-09 fixed issue #9 by adding an SM1210 footprint for a second fuse. It's up to us to decide which kind of fuse to solder in the board, but the PCB has got both footprints.
    [Display.sch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]
2014-12-09 sch: created one sheet for each part of the circuit
    [MOD_Foot_Prototype1.sch, control-chain.sch, cpu.sch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]
2014-12-09 fix issue #4: sch: full duplex control chain circuit done
    [control-chain.sch, display.sch, io.sch]
2014-12-09 sch: applying page settings to all sheets
    [MOD_Foot_Prototype1.sch, control-chain.sch, cpu.sch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]
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2014-12-10 yet about issue #11: sch: pins 9 and 10 are being connected with 0R resitor
    [cpu.sch]
2014-12-10 * fix wrong control-chain signal names * annotate new resistors added to the sch * rearrange sch drawing around header P1
    [control-chain.sch, cpu.sch, display.sch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]
2014-12-10 Fixing schematics references numbering. Also regenerated .net and .cmp files.
    [control-chain.sch, cpu.sch, io.sch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]
2014-12-10 fixing the footprint for the MAX1345 chip.
    [control-chain.sch]
2014-12-10 fix issue #16: fix footprint of 1/2w resistors (The 1/2 W resistores should use the footprint SM1210.)
    [control-chain.sch]
2014-12-10 wip - retracing PCB to accomodate schematic changes from previous recent commits.
    [MOD_Foot_Prototype1.kicad_pcb]
2014-12-10 fix issues #4 and #11 - traced all pcb signals and regenerated Gerber files.
    [MOD_Foot_Prototype1-B_Cu.gbl, MOD_Foot_Prototype1-B_Mask.gbs, MOD_Foot_Prototype1-B_SilkS.gbo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]
2014-12-10 changing the position of the C5 capacitor to make it fit (it was too tight to place it between the RJ45 connectors)
    [MOD_Foot_Prototype1-B_Cu.gbl, MOD_Foot_Prototype1-B_Mask.gbs, MOD_Foot_Prototype1-B_SilkS.gbo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]
2014-12-11 tweaking the pcb layout to avoid islands without copper in the ground plane.
    [MOD_Foot_Prototype1-B_Cu.gbl, MOD_Foot_Prototype1-B_Mask.gbs, MOD_Foot_Prototype1-B_SilkS.gbo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]
2014-12-12 fix issue #1: Add "CC by-SA" license logo to the PCB silk layer
    [MOD_Foot_Prototype1-B_Cu.gbl, MOD_Foot_Prototype1-B_Mask.gbs, MOD_Foot_Prototype1-B_SilkS.gbo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]
2014-12-16 add pull up resistors (to 3V3) to the LCD ENABLE and RW signals (wip issue #10)
    [control-chain.sch, cpu.sch, display.sch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]
2014-12-16 fix issue #10: updating the PCB layout with the added pull up resistors for LCD ENABLE and RW signals
    [MOD_Foot_Prototype1-B_Cu.gbl, MOD_Foot_Prototype1-B_Mask.gbs, MOD_Foot_Prototype1-B_SilkS.gbo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]
2014-12-17 Adding 3.3V reference voltage Vl to MAX13450E. Also changing the pull up voltage from 5V to 3.3V on the R0 and TERM100 signals.
    [control-chain.sch]
2014-12-17 Modifying the control chain RTERM_CHAIN circuit to generate a 3.3V logic signal. (instead of 5 volts)
    [control-chain.sch]
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2015-01-07 fixing name of the standard RS-485 -> RS-422
    [control-chain.sch, footswitch.kicad_pcb]
2015-01-07 using RJ45 leds to indicate cable connection status instead of power status
    [control-chain.sch, cpu.sch, display.sch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]
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2015-06-23 importing common sheets from expression-pedal project
    [control-chain.sch, cpu.sch, display.sch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]
2015-06-23 sch: schematic updated (missing displays circuit)
    [control-chain.sch, cpu.sch, display.sch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]
2015-06-24 sch: display circuit done
    [control-chain.sch, cpu.sch, display.sch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]
2015-06-24 sch: MPN added to all components
    [cpu.sch, display.sch, footswitch.csv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]
2015-06-25 sch: fixing VBUS signal and FS1 I/O
    [control-chain.sch, cpu.sch, display.sch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]
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2015-07-23 sch: added mechanic sheet
    [control-chain.sch, cpu.sch, display.sch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]
2015-07-23 added keystones to mechanic
    [mechanic.sch]
2015-07-23 sch: fixing some footprints and MPN
    [cpu.sch, footswitch.csv, io.sch]
2015-07-23 pcb: importing board dxf files
    [footswitch.kicad_pcb]
2015-07-23 sch: kicad libray updated + missing footprints added
    [Mechanic.sch, io.sch]
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2015-07-23 sch: channel selector switch is no longer used
    [cpu.sch, display.sch, io.sch]
2015-07-23 pcb: importing netlist after remove channel selector
    [footswitch.kicad_pcb]
2015-07-23 sch: fixing mechanic sheet
    [footswitch.sch, mechanic.sch]
2015-07-23 sch: increasing display holes
    [display.sch]
2015-07-23 pcb: initial placement of footprint with mandatory position
    [footswitch.kicad_pcb]
2015-07-24 sch: schematic files reorganized, new sheets for usb and rear board
    [Mechanic.sch, control-chain.sch, cpu.sch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]
2015-07-24 pcb: rear board layout done
    [footswitch.kicad_pcb]
2016-06-13 fix power voltage
    [power.sch, rear-board.sch, usb.sch]
2016-06-13 connecting foot leds directly to cpu
    [cpu.sch, io.sch]
2016-06-13 using now RJ45 connectors without leds
    [rear-board.sch]
2016-06-13 update 'boards connector' signals
    [rear-board.sch]
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2016-06-13 changing footprint of rear board header
    [rear-board.sch]
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2016-06-14 replace reset button by pin header
    [cpu.sch, power.sch, rear-board.sch]
2016-06-14 importing last sch changes
    [footswitch.kicad_pcb]
2016-06-14 initial placement (all footprints)
    [footswitch.kicad_pcb]
2016-06-14 fix usb resistors
    [cpu.sch, rear-board.sch, usb.sch]
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2016-06-14 swapping leds IOs
    [cpu.sch]
2016-06-14 two RGB LEDs connected
    [footswitch.kicad_pcb]
2016-06-15 all LEDs signals connected
    [footswitch.kicad_pcb]
2016-06-15 swapping LCD IOs
    [cpu.sch]
2016-06-15 LCD data signals connected
    [footswitch.kicad_pcb]
2016-06-15 more IOs swapped
    [cpu.sch]
2016-06-15 more LCD signals traced
    [footswitch.kicad_pcb]
2016-06-16 swapping IOs
    [cpu.sch]
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2016-06-16 lot of tracks connected
    [footswitch.kicad_pcb]
2016-06-16 rename 12v line to Vin in the rear board
    [power.sch, rear-board.sch]
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2016-06-16 adding missing MPN
    [mechanic.sch, rear-board.sch]
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2016-07-12 changing one cap PN
    [usb.sch]
2016-07-12 update layout according last RJ45 position
    [footswitch.kicad_pcb]
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2016-07-15 point the LCD voltage in the MPN
    [display.sch]
2016-07-15 use footswitch 1 as trigger to firmware upgrade
    [cpu.sch]
2016-07-15 remove resistors divider of usb vbus
    [usb.sch]
2016-07-18 use fixed contrast to displays
    [cpu.sch, display.sch]
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2016-07-18 update BOM and netlist
    [footswitch.csv]
2016-07-18 only trigger isp when usb is connected
    [cpu.sch, usb.sch]
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2016-07-18 lcd contrast comps connected
    [footswitch.kicad_pcb]
2016-07-18 increase usb vcc pull down resistor
    [usb.sch]
2016-07-18 update layout adding last sch changes
    [footswitch.kicad_pcb]
2017-07-12 sch: fix polarity of lcd backlight mosfets
    [control-chain.sch, cpu.sch, display.sch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]
2017-07-12 sch: replace reset footprint (pin header -> 0402)
    [cpu.sch]
2017-07-12 sch: remove 5V regulator
    [control-chain.sch, cpu.sch, display.sch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]
2017-07-13 sch: control RE pin via uC I/O
    [control-chain.sch, cpu.sch]
2017-07-13 sch: change angled pin header to straight one
    [display.sch, footswitch.sch, io.sch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]
2017-07-14 shc: change RE I/O
    [cpu.sch]
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2018-12-21 decrease res value of display backlight (same footprint); bom updated
    [display.sch, footswitch.csv]
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
